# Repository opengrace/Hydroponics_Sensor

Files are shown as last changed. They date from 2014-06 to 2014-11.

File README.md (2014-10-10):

Hydroponics_Sensor
==================

**Warning** _currently untested, may contain errors._

An ebb and flow hydroponics or CHPIS aquaponics sensor breakout and controller that uses a NRF24L01 module for communication to other nodes or a central server.

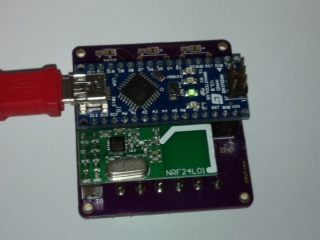
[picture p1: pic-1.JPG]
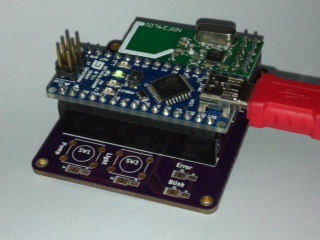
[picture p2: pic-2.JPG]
|||
|---|---|
|Board partially populated.||

[image1]: pic-1.JPG "Arduino nano and 10 pin NRF24L01 module"
[image2]: pic-2.JPG "Arduino nano and 10 pin NRF24L01 module"

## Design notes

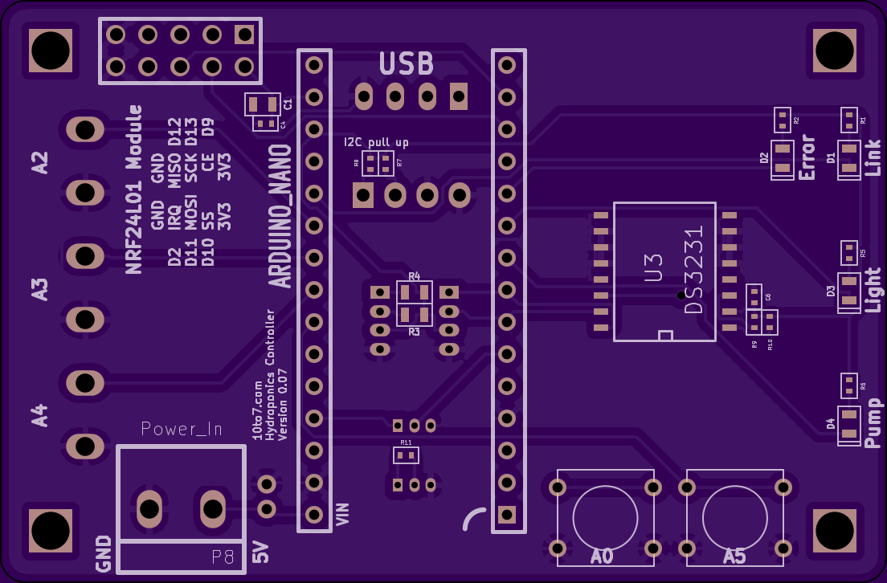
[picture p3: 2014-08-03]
front.png

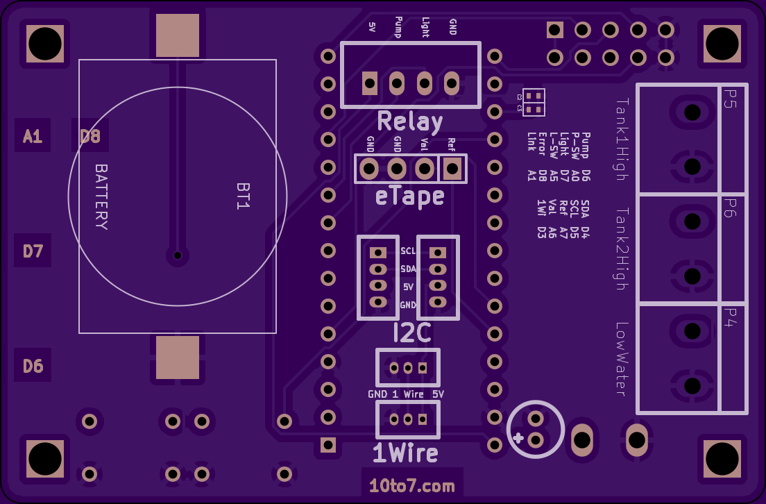
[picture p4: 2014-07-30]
back.png

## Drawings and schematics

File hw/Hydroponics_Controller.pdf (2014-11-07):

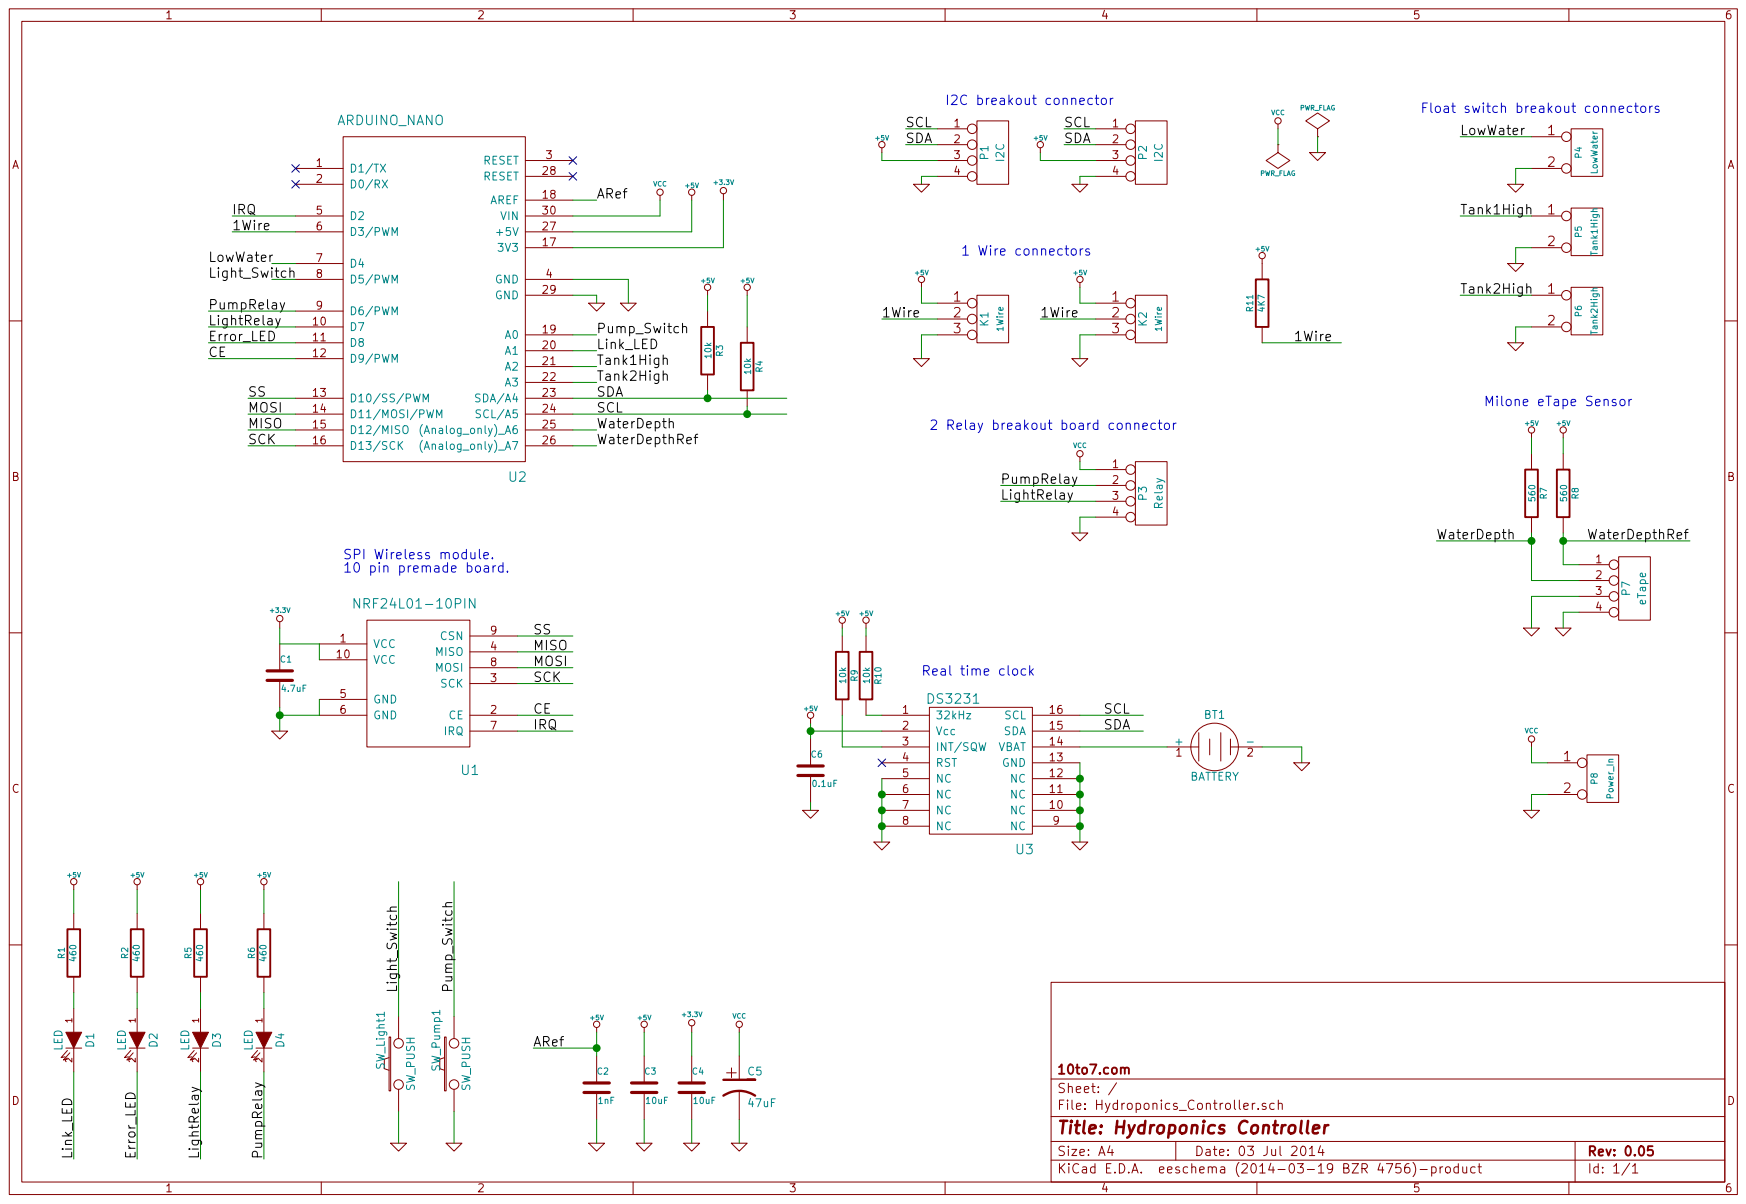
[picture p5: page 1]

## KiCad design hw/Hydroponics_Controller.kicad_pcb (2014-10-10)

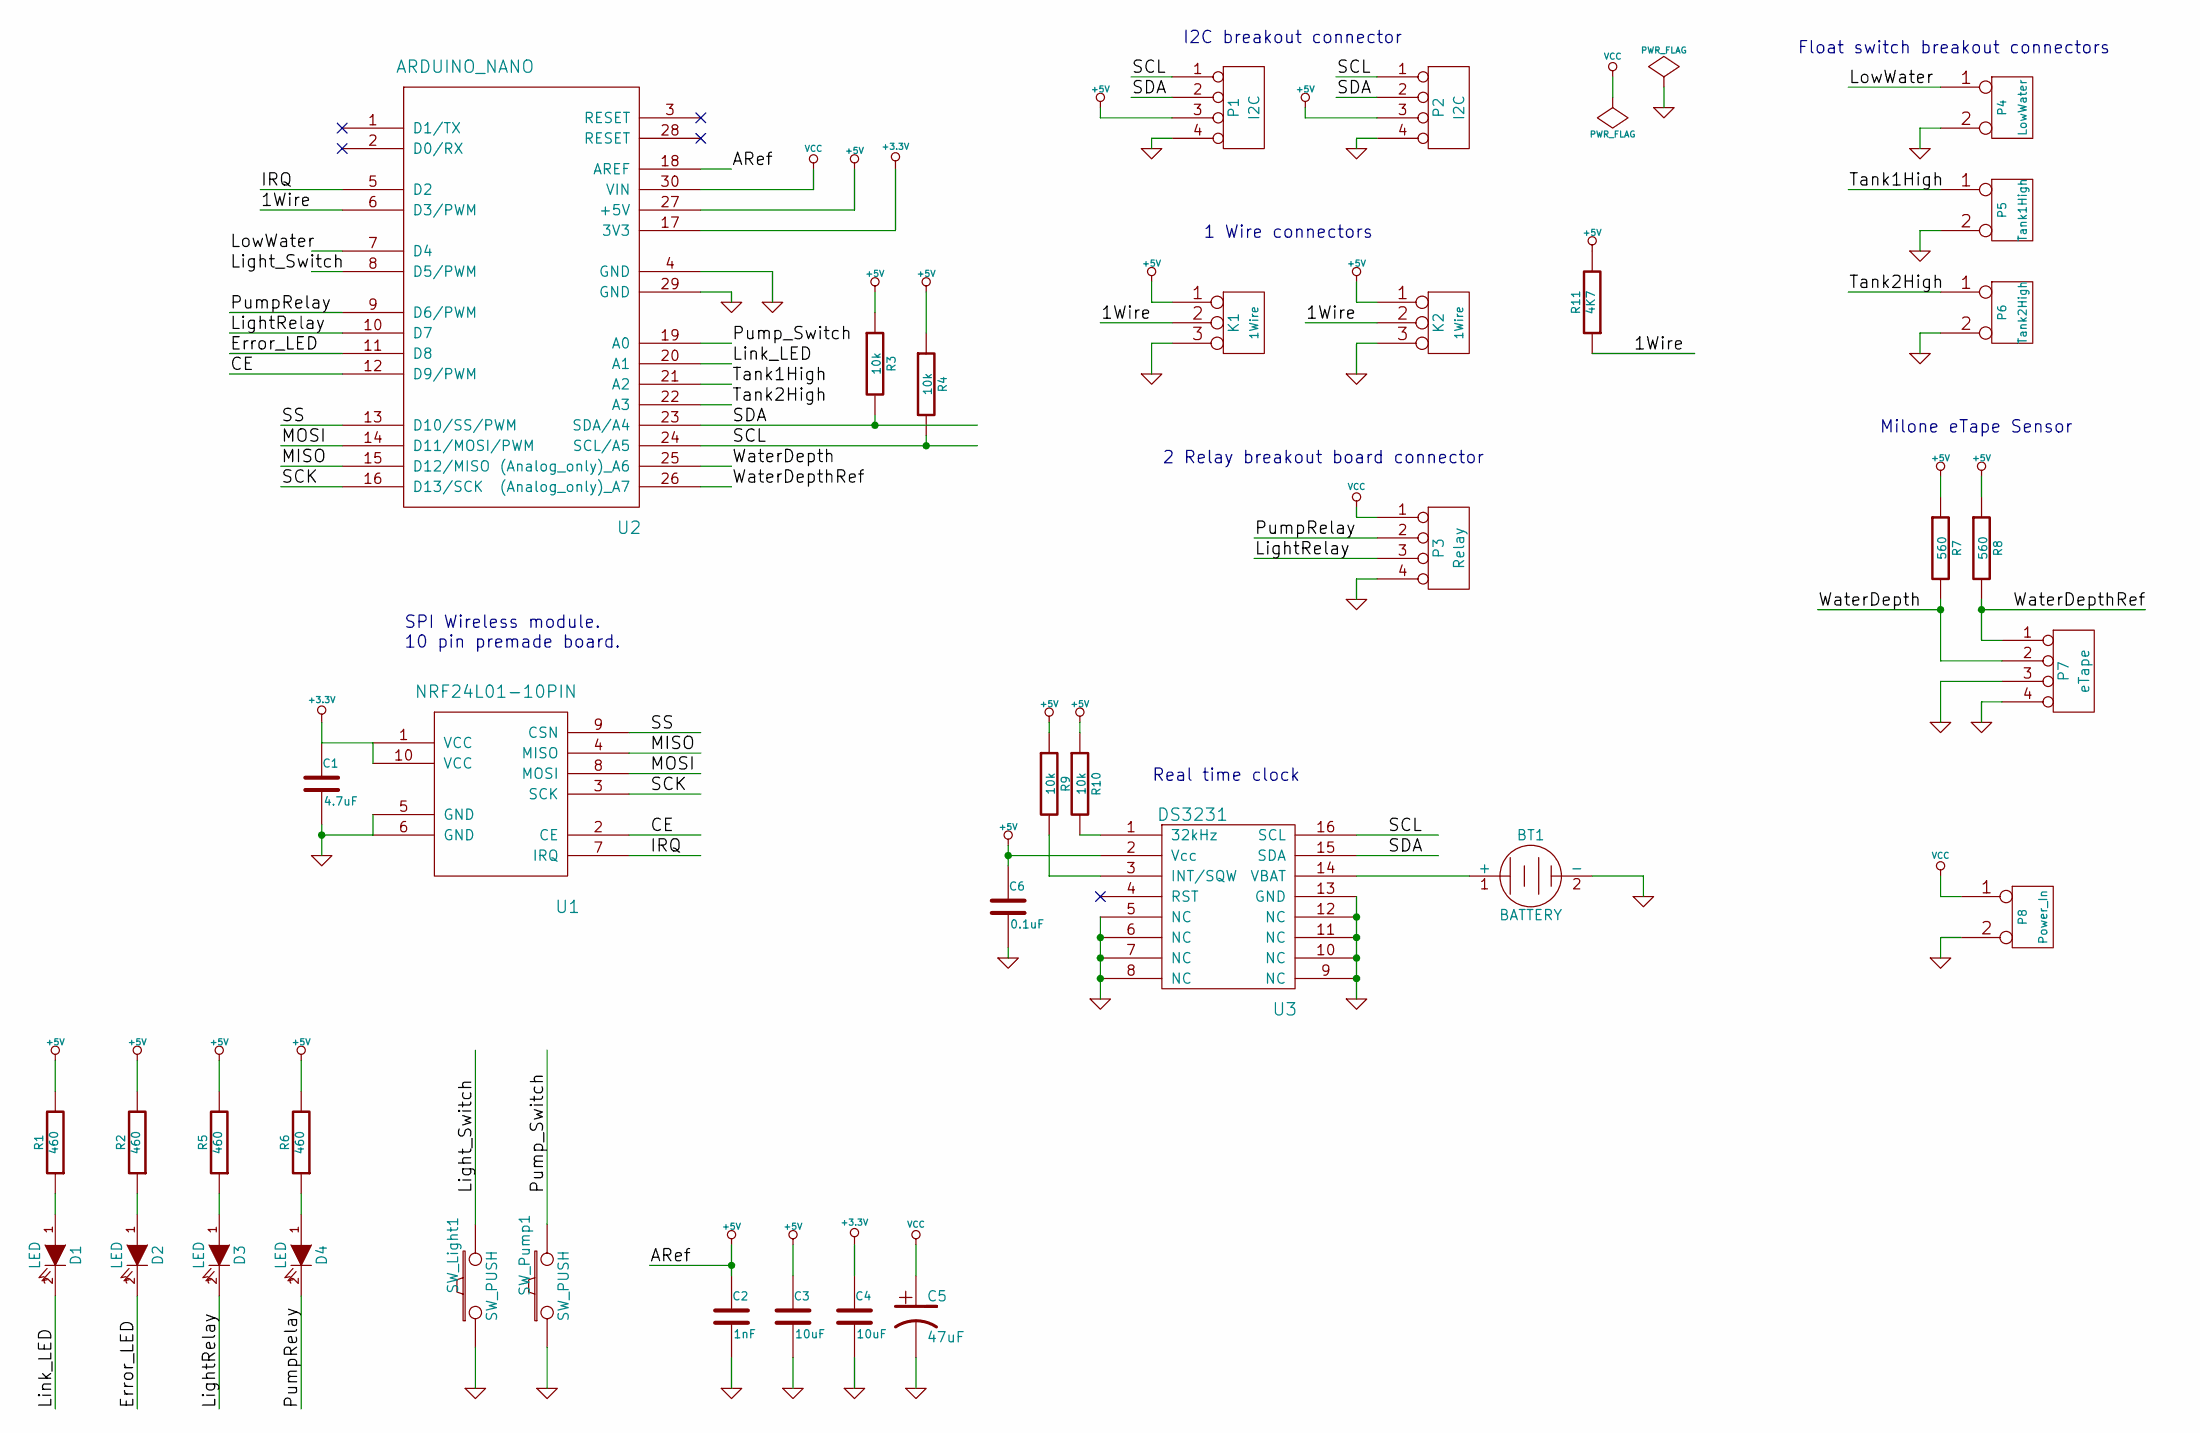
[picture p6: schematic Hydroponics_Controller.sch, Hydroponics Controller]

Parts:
BT1: BATTERY
C1: 4.7uF
C2: 1nF
C3, C4: 10uF
C5: 47uF
C6: 0.1uF
D1, D2, D3, D4: LED
K1, K2: 1Wire
P1, P2: I2C
P3: Relay
P4: LowWater
P5: Tank1High
P6: Tank2High
P7: eTape
P8: Power_In
R1, R2, R5, R6: 460
R3, R4, R9, R10: 10k
R7, R8: 560
R11: 4K7
SW_Light1: SW_PUSH
SW_Pump1: SW_PUSH
U1: NRF24L01-10PIN
U2: ARDUINO_NANO
U3: DS3231

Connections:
+3.3V: C1.1, C4.1, U1.1 (VCC), U1.10 (VCC), U2.17 (3V3)
+5V: C2.1, C3.1, C6.1, K1.1, K2.1, P1.3, P2.3, R1.2, R2.2, R3.1, R4.1, R5.2, R6.2, R7.1, R8.1, R9.1, R10.1, R11.2, U2.18 (AREF), U2.27 (+5V), U3.2 (Vcc)
/1Wire: K1.2 (PM), K2.2 (PM), R11.1, U2.6 (D3/PWM)
/CE: U1.2 (CE), U2.12 (D9/PWM)
/Error_LED: D2.2 (K), U2.11 (D8)
/IRQ: U1.7 (IRQ), U2.5 (D2)
/LightRelay: D3.2 (K), P3.3, U2.10 (D7)
/Light_Switch: SW_Light1.2
/Link_LED: D1.2 (K), U2.20 (A1)
/LowWater: P4.1
/MISO: U1.4 (MISO), U2.15 (D12/MISO)
/MOSI: U1.8 (MOSI), U2.14 (D11/MOSI/PWM)
/PumpRelay: D4.2 (K), P3.2, U2.9 (D6/PWM)
/Pump_Switch: SW_Pump1.2, U2.19 (A0)
/SCK: U1.3 (SCK), U2.16 (D13/SCK)
/SCL: P1.1, P2.1, R4.2, U2.24 (SCL/A5), U3.16 (SCL)
/SDA: P1.2, P2.2, R3.2, U2.23 (SDA/A4), U3.15 (SDA)
/SS: U1.9 (CSN), U2.13 (D10/SS/PWM)
/Tank1High: P5.1, U2.21 (A2)
/Tank2High: P6.1, U2.22 (A3)
/WaterDepth: P7.2, R7.2, U2.25 ((Analog_only)_A6)
/WaterDepthRef: P7.1, R8.2, U2.26 ((Analog_only)_A7)
GND: BT1.2 (-), C1.2, C2.2, C3.2, C4.2, C5.2, C6.2, K1.3, K2.3, P1.4, P2.4, P3.4, P4.2 (PM), P5.2 (PM), P6.2 (PM), P7.3, P7.4, P8.2 (PM), SW_Light1.1, SW_Pump1.1, U1.5 (GND), U1.6 (GND), U2.4 (GND), U2.29 (GND), U3.5 (NC), U3.6 (NC), U3.7 (NC), U3.8 (NC), U3.9 (NC), U3.10 (NC), U3.11 (NC), U3.12 (NC), U3.13 (GND)
unnamed: BT1.1 (+), U3.14 (VBAT)
unnamed: D1.1 (A), R1.1
unnamed: D2.1 (A), R2.1
unnamed: D3.1 (A), R5.1
unnamed: D4.1 (A), R6.1
unnamed: R9.2, U3.3 (INT/SQW)
unnamed: R10.2, U3.1 (32kHz)
VCC: C5.1, P3.1, P8.1, U2.30 (VIN)

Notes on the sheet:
SPI Wireless module. 10 pin premade board.
Float switch breakout connectors
Milone eTape Sensor
I2C breakout connector
1 Wire connectors
2 Relay breakout board connector
Real time clock

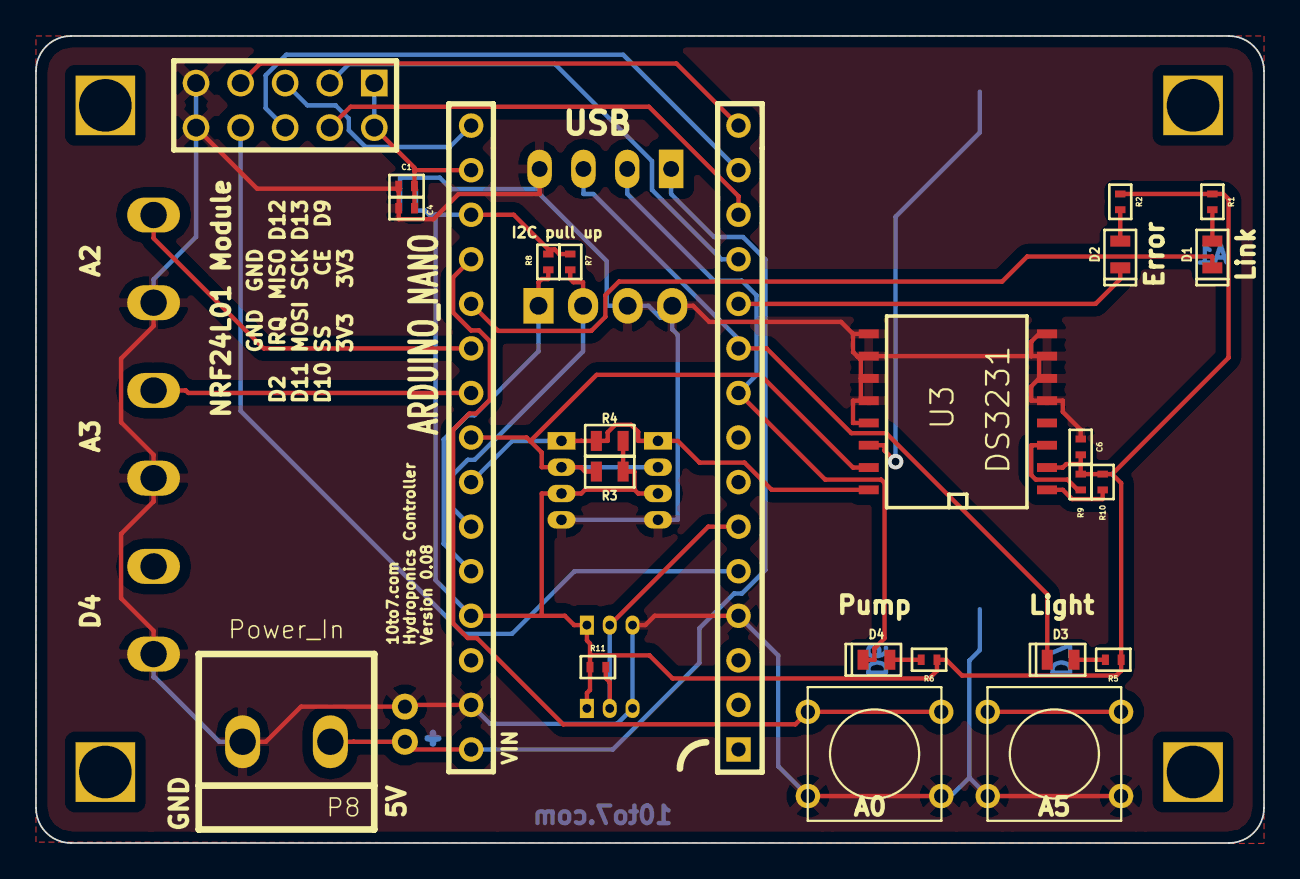
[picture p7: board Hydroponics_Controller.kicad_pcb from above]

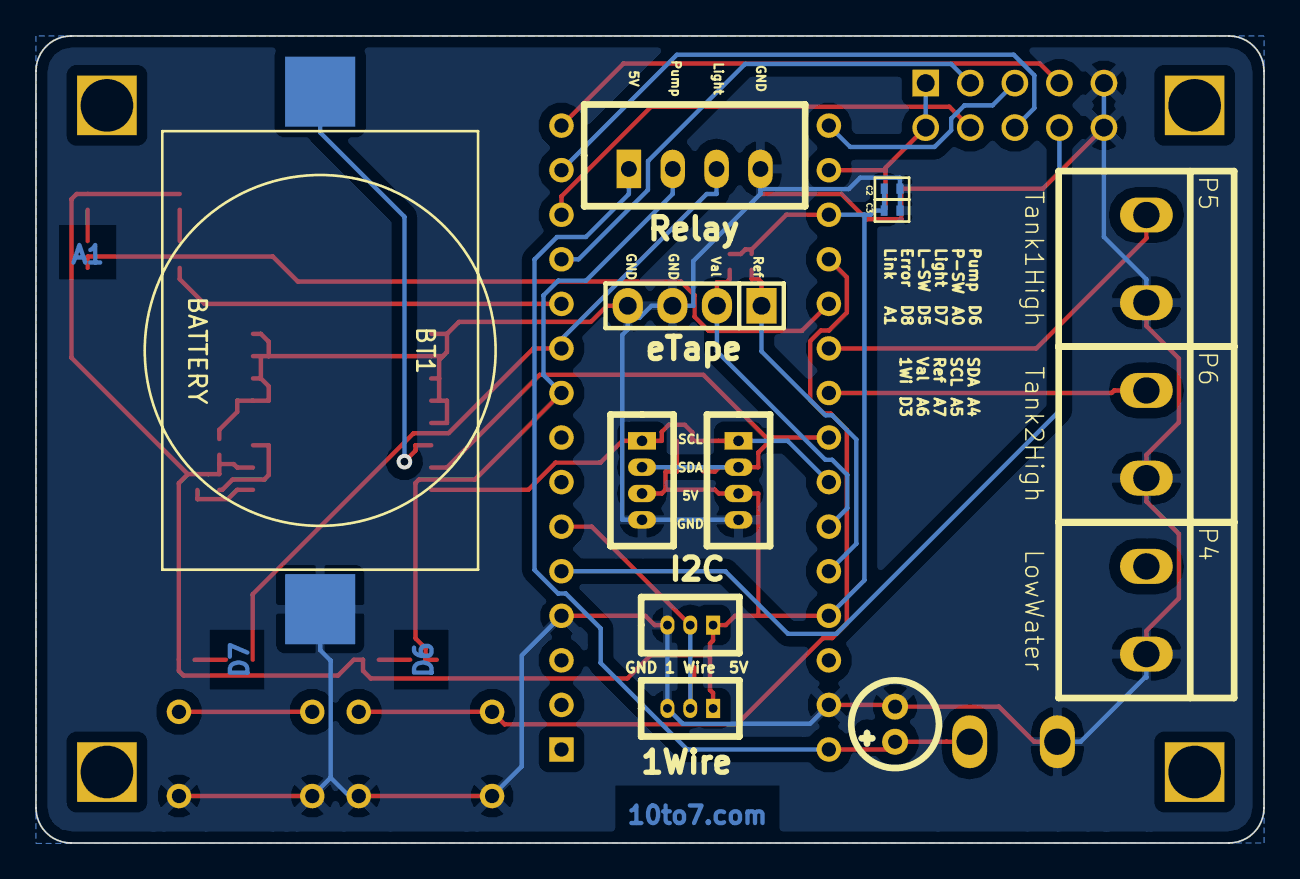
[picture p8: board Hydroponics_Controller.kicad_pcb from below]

Board: 2 copper layers, 70.0 x 46.0 mm, 41 parts (13 on the bottom side), 29 nets.

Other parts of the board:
3mmHole_1, 3mmHole_2, 3mmHole_3, 3mmHole_4: VAL**; 3mmHole

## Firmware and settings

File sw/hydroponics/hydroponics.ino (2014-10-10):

#include <SPI.h>
#include "nRF24L01.h"
#include "RF24.h"
#include <Time.h>
#include <TimeAlarms.h>
#include <Wire.h>
#include <DS1307RTC.h>

#define RF_SETUP 0x17

RF24 radio(9,10);
const uint64_t pipes[2] = { 0xF0F0F0F0E1LL, 0x7365727631LL };
char receivePayload[32];
uint8_t counter=0;


const int lightPin = 7; //D7
const int pumpPin = 6; //D6
const int errorLED = 8; //D8
const int blinkLED = A1; //A1
const int eTapeRef = A7; //A7
const int eTape = A6; //A6
const int pumpSwitch = A0; //A0
const int lightSwitch = A5; //A5
const int lowWater = A4;//A4
const int tankOne = A2;//A2
const int tankTwo = A3;//A3

const float minTape = 761;
const float maxTape = 118.92;

int pumpState = 0;
int lightState = 0;
int tankOneState = 0;
int tankTwoState = 0;
int lowWaterState = 0;
int lastpumpSwitchState = 0;
int lastLightSwitchState = 0;

int notEnoughWater = 0;

void setup(void) {
	Serial.begin(9600);
	
	setupRadio();
	if(getDate()) {
		// create the alarms
		Alarm.alarmRepeat(6,0,0, MorningAlarm);  // 0600 every day
		Alarm.alarmRepeat(22,00,0, EveningAlarm);  // 2200 every day
		if(hour() > 6 || hour() < 22) {
			MorningAlarm();
			} else {
			EveningAlarm();
		}
	}
	
	pinMode(pumpSwitch, INPUT);
	pinMode(lightSwitch, INPUT);
	pinMode(lowWater, INPUT);
	pinMode(tankOne, INPUT);
	pinMode(tankTwo, INPUT);
	
	pinMode(pumpPin, OUTPUT);
	pinMode(lightPin, OUTPUT);
	pinMode(errorLED, OUTPUT);
	pinMode(blinkLED, OUTPUT);
	
	digitalWrite(pumpSwitch, HIGH);
	digitalWrite(lightSwitch, HIGH);
	digitalWrite(lowWater, HIGH);
	digitalWrite(tankOne, HIGH);
	digitalWrite(tankTwo, HIGH);
	digitalWrite(blinkLED, HIGH);
	
	digitalWrite(lightPin, HIGH);
	digitalWrite(pumpPin, HIGH);
}

void loop(void) {
	pumpProcesses();
	lightProcess();
	Alarm.delay(100);
	
}

void MorningAlarm() {
	Serial.println("Morning Alarm");
	digitalWrite(lightPin, LOW);
	digitalWrite(pumpPin, LOW);
	// make sure we have the right time;
	getDate();
}

void EveningAlarm() {
	Serial.println("Evening Alarm");
	digitalWrite(lightPin, HIGH);
	// make sure we have the right time;
	getDate();
}

void setupRadio() {
	radio.begin();

	// Enable this seems to work better
	radio.enableDynamicPayloads();

	radio.setDataRate(RF24_1MBPS);
	radio.setPALevel(RF24_PA_MAX);
	radio.setChannel(76);
	radio.setRetries(15,15);

	radio.openWritingPipe(pipes[0]);
	radio.openReadingPipe(1,pipes[1]);

	
	// Send only, ignore listening mode
	//radio.startListening();

	// Dump the configuration of the rf unit for debugging
	radio.printDetails();
}

boolean getDate() {
	char outBuffer[32]=""; // Clear the outBuffer before every loop
	unsigned long send_time, rtt = 0;
	bool timeout=0;
	send_time = millis();
	strcat(outBuffer,"Get Time");
	// Stop listening and write to radio
	radio.stopListening();
	
	// Send to hub
	digitalWrite(blinkLED, LOW);
	if ( radio.write( outBuffer, strlen(outBuffer)) ) {
		Serial.println("Send Time Request: successful\n\r");
	}
	else {
		Serial.println("Send Time Request: failed\n\r");
	}
	digitalWrite(blinkLED, HIGH);
	
	radio.startListening();
	delay(20);
	
	while ( radio.available() && !timeout ) {
		uint8_t len = radio.getDynamicPayloadSize();
		radio.read( receivePayload, len);
		
		receivePayload[len] = 0;
		if (len == 19) {
			setTimeFromChar(receivePayload);
			
			rtt = millis() - send_time;
			Serial.println("Time set");
			
			return true;
			
			} else {
			Serial.print("Send Time Request: unexpected response: ");
			Serial.println(receivePayload);
		}
		//Serial.print("inBuffer --> rtt: ");
		//Serial.println(rtt);
		
		// Check for timeout and exit the while loop
		if ( millis() - send_time > radio.getMaxTimeout() ) {
			Serial.println("Timeout!!!");
			timeout = 1;
		}
		delay(10);
	} // End while
	
	return false;
}

void setTimeFromChar(char* date) {
	char cHour[] = { date[11], date[12], 0 };
	char cMin[] = { date[14], date[15], 0 };
	char cSec[] = { date[17], date[18], 0 };
	char cDay[] = { date[8], date[9], 0 };
	char cMonth[] = { date[5], date[6], 0 };
	char cYear[] = { date[2], date[3], 0 };
	
	Serial.println(date);
	
	Serial.print(" Hour : ");
	Serial.print(cHour);
	Serial.print(" Min : ");
	Serial.print(cMin);
	Serial.print(" Sec : ");
	Serial.print(cSec);
	Serial.print(" Day :  ");
	Serial.print(cDay);
	Serial.print(" Month : ");
	Serial.print(cMonth);
	Serial.print(" Year : ");
	Serial.println(cYear);
	
	setTime(atoi(cHour), atoi(cMin), atoi(cSec), atoi(cDay), atoi(cMonth), atoi(cYear));
}

void lightProcess(){
	lightState = digitalRead(lightSwitch);
	int lightChanged = (lastLightSwitchState != digitalRead(lightSwitch));
	lastLightSwitchState = digitalRead(lightSwitch);
	
	if(digitalRead(lightPin) == HIGH) {
		if(digitalRead(lightSwitch) == LOW
		&& lightChanged == HIGH) {
			digitalWrite(lightPin, LOW);
		}
		} else {
		if (lightChanged == HIGH
		&& lastLightSwitchState == LOW) {
			digitalWrite(lightPin, HIGH);
		}
	}
}
void pumpProcesses() {
	pumpState = digitalRead(pumpPin);
	
	tankOneState = digitalRead(tankOne);
	tankTwoState = digitalRead(tankTwo);
	lowWaterState = digitalRead(lowWater);
	
	int pumpChanged = (lastpumpSwitchState != digitalRead(pumpSwitch));
	lastpumpSwitchState = digitalRead(pumpSwitch);
	/*
	Serial.print("Switch state : ");
	Serial.print(pumpState);
	Serial.print(lightState);
	Serial.print(tankOneState);
	Serial.print(tankTwoState);
	Serial.print(lowWaterState);
	Serial.println(pumpChanged);
	*/
	if(checkTankState() == true) {
		if(digitalRead(pumpPin) == HIGH) {
			if(digitalRead(pumpSwitch) == LOW
			&& pumpChanged == HIGH) {
				digitalWrite(pumpPin, LOW);
			}
			} else {
			if (pumpChanged == HIGH
			&& lastpumpSwitchState == LOW) {
				digitalWrite(pumpPin, HIGH);
			}
		}
		} else {
		digitalWrite(pumpPin, HIGH);
	}
	
	if(notEnoughWater == 1) {
		digitalWrite(errorLED, !digitalRead(errorLED));
		} else {
		digitalWrite(errorLED, HIGH);
	}
	
}

boolean checkTankState(){
	if(lowWaterState == HIGH) {
		if(digitalRead(pumpPin) == LOW) {
			Serial.println("WARNING: Not enough water to complete the pump cycle.");
		}
		notEnoughWater = 1;
		return false;
	}
	
	if(tankOneState == LOW
	|| tankTwoState == LOW) {
		notEnoughWater = 0;
		if(digitalRead(pumpPin) == LOW) {
			Serial.println("Watercycle complete.");
		}
		return false;
	}
	return true;
}
/*
float reading;
float ref;

reading = analogRead(A0);
ref = analogRead(A1);
Serial.print("Analog read: ");
Serial.print(reading);
Serial.print(" : ");
Serial.println(ref);

reading = (1023 / reading) -1;
reading = 540 / reading;
ref = (1023 / ref) -1;
ref = 540 / ref;

Serial.print("Sensor resistance: ");
Serial.print(reading);
Serial.print(" : ");
Serial.println(ref);

reading = reading - 300;
reading = 22.8-  (reading / 56) ;
Serial.print("Distance in cm: ");
Serial.println(reading);

delay(1000);
*/

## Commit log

2014-05-18 Recreated and moved to new repository
    [project.brd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]
2014-05-31 removed some un-needed components, updated faulty modules and reduced board size.
    [project.brd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]
2014-05-31 and the gerber files
    [project-B_Cu.gbl, project-B_Mask.gbs, project-B_SilkS.gbo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]
2014-06-01 Fixed text consistency issue in the silkscreen.
    [project.brd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]
2014-06-04 revision 0.03 - update due to the error in the arduino nano footprint
    [project.brd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]
2014-06-26 Added some images of a partially created board.
2014-06-30 Added 3mm mount holes and moved the pull-up resistor. Corrected inconsistency with the netlist and the schematic
    [project.brd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]
2014-06-30 moved the pcb silkscreen of the etape
    [project.brd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]
2014-06-30 another silkscreen error fixed
    [project.brd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]
2014-07-02 Added PCB images
2014-07-02 Something wierd is happening with Kicad. GND nets were appearing as VCC in PCB new.
    [project.brd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]
2014-07-05 remade the board. Something went wrong with ki-cad and the mask wasn't fitting correctly.
    [Hydroponics_Controller-B_Cu.gbl, Hydroponics_Controller-B_Mask.gbs, Hydroponics_Controller-B_SilkS.gbo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]
2014-07-05 fixed small error on the silk screen
    [Hydroponics_Controller.kicad_pcb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]
2014-07-27 Added RTC to board. Corrected error using A6/A7 as digital pins...
    [Hydroponics_Controller-B_Cu.gbl, Hydroponics_Controller-B_Mask.gbs, Hydroponics_Controller-B_SilkS.gbo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]
2014-07-28 Some basic functionality added - pump cycle, low water and date from wireless.
2014-07-28 logic fail in the setup call to the alarms. alarm.Delay also missing.
    [hydroponics.ino]
2014-07-29 Alarms doesn't seem to play nice with another library, removed it and added simple logic which should give similar results
    [hydroponics.ino]
2014-07-30 Updated the PCB render
2014-08-01 overrun was being over zealous and prevented all pump activity after the maxPumpRun time following a reset.
    [hydroponics.ino]
2014-08-03 Fixed the missing pullup resistor from the 1 wire connector
    [Hydroponics_Controller-B_Cu.gbl, Hydroponics_Controller-B_Mask.gbs, Hydroponics_Controller-B_SilkS.gbo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]
2014-09-13 Script updated to reflect the pin changes in version 0.7. Note still in development.
2014-09-27 Enabled the light button
    actually made the light button functional.
2014-10-10 updated to fix I2C connected to wrong pins. Also changed cap to 0402
    [Hydroponics_Controller-B_Cu.gbl, Hydroponics_Controller-B_Mask.gbs, Hydroponics_Controller-B_SilkS.gbo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]
2014-11-07 Added pdf of the schematic
